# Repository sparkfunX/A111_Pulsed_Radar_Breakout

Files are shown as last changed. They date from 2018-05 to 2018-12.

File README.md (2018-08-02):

SparkX A111 Pulsed Radar Breakout
========================================

SparkX A111 Pulsed Radar Breakout (https://www.sparkfun.com/products/14811)

[*SparkX  A111 Pulsed Radar Breakout (SPX-14811)*](https://www.sparkfun.com/products/14811)

Does your project require high-precision, cutting-edge distance measurement? Or maybe speed-, motion-, or gesture-sensing? We’re not talking about simple ultrasonic, or even infrared, sensors here, but 60GHz radar! Well say hello to our tiny, pulsed-radar friend: the Acconeer A111.

The A111 is a single-chip solution for pulsed coherent radar (PCR). It comes complete with integrated antennae and an SPI interface capable of clock speeds of up to 50MHz. The A111’s primary use case is distance-sensing, but it also supports applications in gesture-, motion-, material-, and speed-detection. It can see objects at distances of up to two meters.

Our breakout board for the A111 includes a 1.8V regulator, voltage-level translation between 1.8V and either 3.3V or 5V, and, of course, it breaks out all pins of the pulsed radar sensor to both 0.1-inch and Raspberry Pi-friendly headers.

The breakout board is primarily **designed to interface directly with a Raspberry Pi** – Acconeer’s SDK currently only supports ARMv7’s (e.g. a Pi) and ARM Cortex-M4’s. Check out our <a href="https://learn.sparkfun.com/tutorials/using-the-a111-pulsed-radar-sensor-with-a-raspberry-pi">Using the A111 Pulsed Radar Breakout tutorial</a>, which explains how to use the sensor with a Raspberry Pi.

SparkFun labored with love to create this code. Feel like supporting open source hardware? 
Buy a [breakout board](https://www.sparkfun.com/products/14811) from SparkFun!

Repository Contents
-------------------

* **/Documents** - Datasheets
* **/Hardware** - Eagle design files (.brd, .sch)
* **/Software** - Example code and board-definition files to be added to the Acconeer ARMv7 SDK

License Information
-------------------

This product is _**open source**_! 

If you have any questions or concerns on licensing, please contact techsupport@sparkfun.com.

Please use, reuse, and modify these files as you see fit. Please maintain attribution to SparkFun Electronics and release any derivative under the same license.

Distributed as-is; no warranty is given.

- Your friends at SparkFun.

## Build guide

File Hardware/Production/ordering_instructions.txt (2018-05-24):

panel size, 148x173mm
PCB thickness, 1.6mm
number of layers, 2
soldermask color, Black
silkscreen color, White
oz copper, 1oz
finish, HASL lead free
stencils, top
pcs per panel, 16

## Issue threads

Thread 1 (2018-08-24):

Clarify that raspberry pi SPI needs to be enabled

ChristoSilvia, 2018-08-24:
I'm going through the tutorial now, and I was stuck when the Acconeer binaries didn't seem to be working.  After a while, I discovered that SPI was diabled by default in Raspbian.  It's easy to enable via "Raspberry" -> Preferences -> Raspberry Pi Configuration -> Interfaces, and clicking "enable" under the "SPI" line

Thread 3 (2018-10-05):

make error using spark example code on A1 SDK 1.3.9

uscgongjianxin, 2018-10-05:
I found the example code provided by Sparkfun was written for an earlier A1 SDK version (1.3.5) and the newer version (1.3.9) might have changed enough that it breaks the build. After I type "make" n terminal, I met this problem.

pi@raspberrypi:~/a111/evk_service_linux_armv7l_xc111_r4a_xr111-3_r1c_a111_r2c $ make
    Linking sparkx_envelope_service_example
lib/libacconeer_a111_r2c.a(acc_sensor_driver.o): In function `acc_hal_sensor_device_register_isr':
/home/anders/repos/sw-main/acconeer/sensor/sensor_driver/acc_sensor_driver.c:157: undefined reference to `acc_board_register_isr'
collect2: error: ld returned 1 exit status
rule/makefile_build_example_service_envelope_rpi_sparkx.inc:10: recipe for target 'out/sparkx_envelope_service_example' failed
make: *** [out/sparkx_envelope_service_example] Error 1

I cannot find the directory shown in the error message.
/home/anders/repos/sw-main/acconeer/sensor/sensor_driver/acc_sensor_driver.c

Does someone successfully build the program and get the radar data?

jkumaran, 2018-10-08:
I made a fork with updates in all 6 files of Software/sparkx-sdk-addon/ folder:
https://github.com/jkumaran/A111_Pulsed_Radar_Breakout
This fixed the problem and I was able to observe the radar results.

seasilvia, 2018-10-08:
I'm doing general troubleshooting, my board might just be dead.  I installed this code and make worked successfully:

```
pi@raspberrypi:~/a111/evk_service_linux_armv7l_xc112 $ make
    Compiling acc_board_rpi_sparkx.c
    Linking sparkx_envelope_service_example
    Linking sparkx_envelope_iq_example
    Linking sparkx_power_bins_example
    Compiling sparkx_detector_distance.c
    Linking sparkx_detector_distance
```

However, running the example service, I got "could not determine version:

```
Acconeer software version v1.3.9
Acconeer RSS version 1.0
13:27:03.832 [ 1669] (I) (rss): Radar system services activated
13:27:03.838 [ 1669] (I) (core_a111_r2c): Unknown sensor version 0x0000
13:27:03.838 [ 1669] (E) (session_sweep_and_processing): Could not determine version for sensor 1
13:27:03.838 [ 1669] (E) (session_sweep_and_processing): Sensor 1 not prepared
13:27:03.838 [ 1669] (I) (session_sweep_and_processing): acc_session_sweep_and_processing_destroy: Destroy confirmed
13:27:03.838 [ 1669] (E) (service_envelope): Session not created
acc_service_create failed
execute_envelope_with_blocking_calls() => (1) Failure unspecified
```

Any ideas? Could I have something misconfigured?

jimblom, 2018-10-09:
@jkumaran Thanks for your help. I've committed some changes that mostly reflect what you've done in your fork in the latest commit -- b114e95.

@seasilvia Can you give it a try with the latest updates to the include/source files?

jimblom, 2018-11-26:
@seasilvia I just pushed some changes in commit c4784f2 that should make the makefile rules and examples compatible with A111 SDK v1.3.11. Give it a try and see if it fixes your board. Feel free to re-open if it's still giving you trouble.

@jkumaran -- Sorry I didn't check this issue first to find your fixes... Thanks for your help!

Closed 2018-11-26.

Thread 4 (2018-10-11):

Coordinates system of A111

uscgongjianxin, 2018-10-11:
Now I obtained outputs like this
Distance detector: Reflections: 5. Seq. nr: 424. (200-700 mm): 648 mm (137), 658 mm (250), 665 mm (255), 676 mm (209), 686 mm (65).

But since I don't know the coordinates system of A111,  I don't know the meaning of the amplitude of the reflection. What is x-axis? What is y-axis? Where is the origin? The amplitude should be an angle between an axis and the line connecting the origin and the object.

pthorell, 2018-11-28:
The A111 sensor measures the reflected energy at different radial distances from the sensor. Good reflectors reflect more energy to the sensor which results in a high amplitude in the received signal.

For more information see chapter 5 in the “Envelope service user guide” [https://download.acconeer.com/doc/Envelope%20Service%20User%20Guide](https://download.acconeer.com/doc/Envelope%20Service%20User%20Guide) .

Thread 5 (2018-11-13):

make error using spark example code on A1 SDK 1.3.11

hpritchett, 2018-11-13:
I am getting this error when I run make:
make: *** No rule to make target 'out/example_service_envelope.o', needed by 'out/sparkx_envelope_service_example'.  Stop.

Using the following sdk:
acconeer_evk_service_linux_armv7l_xc111_r4a_xr111-3_r1c_a111_r2c_v1_3_11

The build only fails if I add the A111_Pulsed_Radar_Breakout software addon.
Does anyone have SDK 1.3.9? Or know what I need to do to fix this?

jimblom, 2018-11-26:
Sorry about the delay. I've made some fixes to the rules and board source files in commit c4784f2.

All examples should be compatible with the latest A111 SDK: v1.3.11.

Closed 2018-11-26.

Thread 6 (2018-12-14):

Please Update for SDK 1.4.0

kbooth-insight, 2018-12-14:
The code doesn't build with the most recent SDK:

```
pi@raspberrypi:~/evk_service_linux_armv7l_xc111_r4a_xr111-3_r1c_a111_r2c $ make
    Compiling acc_board_rpi_sparkx.c
source/acc_board_rpi_sparkx.c: In function ‘acc_board_init’:
source/acc_board_rpi_sparkx.c:177:2: error: too few arguments to function ‘acc_driver_gpio_linux_sysfs_register’
  acc_driver_gpio_linux_sysfs_register(28);
  ^~~~~~~~~~~~~~~~~~~~~~~~~~~~~~~~~~~~
In file included from source/acc_board_rpi_sparkx.c:12:0:
include/acc_driver_gpio_linux_sysfs.h:51:13: note: declared here
 extern void acc_driver_gpio_linux_sysfs_register(uint_fast16_t pin_count, gpio_t *gpio_mem);
             ^~~~~~~~~~~~~~~~~~~~~~~~~~~~~~~~~~~~
makefile:60: recipe for target 'out/obj/acc_board_rpi_sparkx.o' failed
```

I tried setting up the new gpio_t param myself, and I end up hard-locking the Pi.

jimblom, 2018-12-20:
Thanks for the heads up!

I've pushed some new changes to source/acc_board_rpi_sparkx.c in commit dbbd525. Should update the addon files to work with SDK 1.4.0.

Feel free to re-open if it's still giving you trouble.

kbooth-insight, 2018-12-21:
Thanks much for updating!

I'm not sure if I should ask this here or over at the sparkfun forums, but after pulling this update and building, I seem to get calibration errors.  The sensor initializes correctly it seems,

Here is some example output:
```
pi@raspberrypi:~/evk_service_linux_armv7l_xc111_r4a_xr111-3_r1c_a111_r2c/out $ ./sparkx_detector_distance
Acconeer software version v1.4.0
Acconeer RSS version 1.0
20:00:23.271 [10508] (I) (rss): Radar system services activated

A111 Initialized

Press ENTER to run distance detection...
Running distance peak detector in blocking mode
20:00:29.367 [10508] (E) (sensor_protocol): Timeout waiting for interrupt.
20:00:29.367 [10508] (E) (sensor_protocol): Timeout waiting for indication on sensor 1.
20:00:29.368 [10508] (I) (sensor_protocol): Run_status running at : 1c2
20:00:29.368 [10508] (I) (sensor_protocol): Run_status running at : 1c2
20:00:29.368 [10508] (I) (sensor_protocol): Run_status running at : 1c2
<snip>
20:00:29.373 [10508] (I) (sensor_protocol): Run_status running at : 1c2
20:00:29.373 [10508] (I) (sensor_protocol): Run_status running at : 1c2
20:00:29.373 [10508] (I) (sensor_protocol): Interrupt_status_register: 80
20:00:29.373 [10508] (I) (sensor_protocol): WakeupInput[7..0]_wakeup_config: 0 24 0 0 0 0 0 0
20:00:29.373 [10508] (I) (sensor_protocol): Inputmux_wakeupinput[7..0]_config : 0 13 0 0 0 0 0 8
20:00:29.373 [10508] (I) (sensor_protocol): Timer[3..0]_wakeup_config: 0 0 0 0
20:00:29.374 [10508] (I) (sensor_protocol): asic_identity_number: 4370, run_status: 1474, interrupt_status: 80, Scratchpad Config 7: 3
20:00:29.374 [10508] (I) (sensor_protocol): Wakeup_status0_register: 1
20:00:29.374 [10508] (I) (sensor_protocol): asic_error_status : 0
20:00:29.374 [10508] (I) (sensor_protocol): Stack_level_status_register: 0
20:00:29.374 [10508] (I) (sensor_protocol): Stack level 0: Addr=450
20:00:29.374 [10508] (I) (sensor_protocol): Stack level 1: Addr=449 Loop=0
20:00:29.374 [10508] (I) (sensor_protocol): Stack level 2: Addr=468 Loop=0
20:00:29.374 [10508] (I) (sensor_protocol): Stack level 3: Addr=0 Loop=0
20:00:29.374 [10508] (I) (sensor_protocol): Stack level 4: Addr=0 Loop=0
20:00:29.374 [10508] (I) (sensor_protocol): Stack level 5: Addr=0 Loop=0
20:00:29.374 [10508] (I) (sensor_protocol): Stack level 6: Addr=0 Loop=0
20:00:29.374 [10508] (I) (sensor_protocol): Stack level 7: Addr=0 Loop=0
20:00:29.374 [10508] (I) (sensor_protocol): vco_cbank_config: 4
20:00:29.374 [10508] (I) (sensor_protocol): pll_config: 127
20:00:29.374 [10508] (I) (sensor_protocol): Pll_div_config: 9
20:00:29.375 [10508] (E) (cbank_calibration_manager): Failed to retrieve indication.
20:00:29.375 [10508] (E) (cbank_calibration_manager): Failed to get result.
20:00:29.375 [10508] (E) (core_a111_r2c): CBank calibration failure.
20:00:29.375 [10508] (E) (session_sweep_and_processing): Sensor calibration failure for sensor 1.
Free space absolute offset: 4294967295 mm
Actual start: 4294967295 mm
Actual length: 4294967295 mm
Actual end: 4294967295 mm

20:00:29.375 [10508] (E) (service): Configuration: Invalid handle.
acc_service_activate() failed
20:00:29.375 [10508] (E) (service): Configuration: Invalid handle.
Running distance peak detector in blocking mode failed
Press ENTER to calculate THRESHOLD and run peak detection...
Running distance peak detector in blocking mode with estimated threshold
20:00:42.455 [10508] (E) (sensor_protocol): Timeout waiting for interrupt.
20:00:42.455 [10508] (E) (sensor_protocol): Timeout waiting for indication on sensor 1.
20:00:42.455 [10508] (I) (sensor_protocol): Run_status running at : 1c2
20:00:42.455 [10508] (I) (sensor_protocol): Run_status running at : 1c2
20:00:42.455 [10508] (I) (sensor_protocol): Run_status running at : 1c2
20:00:42.455 [10508] (I) (sensor_protocol): Run_status running at : 1c2
<snip>
20:00:42.460 [10508] (I) (sensor_protocol): Run_status running at : 1c2
20:00:42.460 [10508] (I) (sensor_protocol): Run_status running at : 1c2
20:00:42.460 [10508] (I) (sensor_protocol): Run_status running at : 1c2
20:00:42.460 [10508] (I) (sensor_protocol): Interrupt_status_register: 80
20:00:42.461 [10508] (I) (sensor_protocol): WakeupInput[7..0]_wakeup_config: 0 24 0 0 0 0 0 0
20:00:42.461 [10508] (I) (sensor_protocol): Inputmux_wakeupinput[7..0]_config : 0 13 0 0 0 0 0 8
20:00:42.461 [10508] (I) (sensor_protocol): Timer[3..0]_wakeup_config: 0 0 0 0
20:00:42.461 [10508] (I) (sensor_protocol): asic_identity_number: 4370, run_status: 1474, interrupt_status: 80, Scratchpad Config 7: 3
20:00:42.461 [10508] (I) (sensor_protocol): Wakeup_status0_register: 1
20:00:42.461 [10508] (I) (sensor_protocol): asic_error_status : 0
20:00:42.461 [10508] (I) (sensor_protocol): Stack_level_status_register: 0
20:00:42.461 [10508] (I) (sensor_protocol): Stack level 0: Addr=450
20:00:42.461 [10508] (I) (sensor_protocol): Stack level 1: Addr=449 Loop=0
20:00:42.461 [10508] (I) (sensor_protocol): Stack level 2: Addr=468 Loop=0
20:00:42.461 [10508] (I) (sensor_protocol): Stack level 3: Addr=0 Loop=0
20:00:42.462 [10508] (I) (sensor_protocol): Stack level 4: Addr=0 Loop=0
20:00:42.462 [10508] (I) (sensor_protocol): Stack level 5: Addr=0 Loop=0
20:00:42.462 [10508] (I) (sensor_protocol): Stack level 6: Addr=0 Loop=0
20:00:42.462 [10508] (I) (sensor_protocol): Stack level 7: Addr=0 Loop=0
20:00:42.462 [10508] (I) (sensor_protocol): vco_cbank_config: 4
20:00:42.462 [10508] (I) (sensor_protocol): pll_config: 127
20:00:42.462 [10508] (I) (sensor_protocol): Pll_div_config: 9
20:00:42.462 [10508] (E) (cbank_calibration_manager): Failed to retrieve indication.
20:00:42.462 [10508] (E) (cbank_calibration_manager): Failed to get result.
20:00:42.462 [10508] (E) (core_a111_r2c): CBank calibration failure.
20:00:42.462 [10508] (E) (session_sweep_and_processing): Sensor calibration failure for sensor 1.
Free space absolute offset: 4294967295 mm
Actual start: 4294967295 mm
Actual length: 4294967295 mm
Actual end: 4294967295 mm

Estimating threshold...
20:00:42.462 [10508] (E) (service): Configuration: Invalid handle.
20:00:42.462 [10508] (E) (acc_detector_distance_peak): Threshold estimation update failed
Estimating threshold done...

Press ENTER to measure threshold-ed distance
Then press CTRL+C to STOP

20:00:46.345 [10508] (E) (service): Configuration: Invalid handle.
acc_service_activate() failed
20:00:46.345 [10508] (W) (acc_detector_distance_peak): Detector is already inactive
20:00:46.345 [10508] (E) (service): Configuration: Invalid handle.
20:00:46.345 [10508] (I) (rss): Radar system services deactivated
```

Any help would be greatly appreciated!

jimblom, 2018-12-21:
Oof, at a glance, I'm not sure -- haven't seen those errors before.

If you don't mind opening a new issue with this, I'd be happy to look into it.

Closed 2018-12-20.

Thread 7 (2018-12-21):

Calibration error using SDK 1.4

kbooth-insight, 2018-12-21:
Opening new issue per advice, really appreciate the assistance.   If you haven't seen this error before, I'm leaning towards my soldering job :(

I'm not sure if I should ask this here or over at the sparkfun forums, but after pulling this update and building, I seem to get calibration errors. The sensor initializes correctly it seems,

Here is some example output:

```
pi@raspberrypi:~/evk_service_linux_armv7l_xc111_r4a_xr111-3_r1c_a111_r2c/out $ ./sparkx_detector_distance
Acconeer software version v1.4.0
Acconeer RSS version 1.0
20:00:23.271 [10508] (I) (rss): Radar system services activated

A111 Initialized

Press ENTER to run distance detection...
Running distance peak detector in blocking mode
20:00:29.367 [10508] (E) (sensor_protocol): Timeout waiting for interrupt.
20:00:29.367 [10508] (E) (sensor_protocol): Timeout waiting for indication on sensor 1.
20:00:29.368 [10508] (I) (sensor_protocol): Run_status running at : 1c2
20:00:29.368 [10508] (I) (sensor_protocol): Run_status running at : 1c2
20:00:29.368 [10508] (I) (sensor_protocol): Run_status running at : 1c2
<snip>
20:00:29.373 [10508] (I) (sensor_protocol): Run_status running at : 1c2
20:00:29.373 [10508] (I) (sensor_protocol): Run_status running at : 1c2
20:00:29.373 [10508] (I) (sensor_protocol): Interrupt_status_register: 80
20:00:29.373 [10508] (I) (sensor_protocol): WakeupInput[7..0]_wakeup_config: 0 24 0 0 0 0 0 0
20:00:29.373 [10508] (I) (sensor_protocol): Inputmux_wakeupinput[7..0]_config : 0 13 0 0 0 0 0 8
20:00:29.373 [10508] (I) (sensor_protocol): Timer[3..0]_wakeup_config: 0 0 0 0
20:00:29.374 [10508] (I) (sensor_protocol): asic_identity_number: 4370, run_status: 1474, interrupt_status: 80, Scratchpad Config 7: 3
20:00:29.374 [10508] (I) (sensor_protocol): Wakeup_status0_register: 1
20:00:29.374 [10508] (I) (sensor_protocol): asic_error_status : 0
20:00:29.374 [10508] (I) (sensor_protocol): Stack_level_status_register: 0
20:00:29.374 [10508] (I) (sensor_protocol): Stack level 0: Addr=450
20:00:29.374 [10508] (I) (sensor_protocol): Stack level 1: Addr=449 Loop=0
20:00:29.374 [10508] (I) (sensor_protocol): Stack level 2: Addr=468 Loop=0
20:00:29.374 [10508] (I) (sensor_protocol): Stack level 3: Addr=0 Loop=0
20:00:29.374 [10508] (I) (sensor_protocol): Stack level 4: Addr=0 Loop=0
20:00:29.374 [10508] (I) (sensor_protocol): Stack level 5: Addr=0 Loop=0
20:00:29.374 [10508] (I) (sensor_protocol): Stack level 6: Addr=0 Loop=0
20:00:29.374 [10508] (I) (sensor_protocol): Stack level 7: Addr=0 Loop=0
20:00:29.374 [10508] (I) (sensor_protocol): vco_cbank_config: 4
20:00:29.374 [10508] (I) (sensor_protocol): pll_config: 127
20:00:29.374 [10508] (I) (sensor_protocol): Pll_div_config: 9
20:00:29.375 [10508] (E) (cbank_calibration_manager): Failed to retrieve indication.
20:00:29.375 [10508] (E) (cbank_calibration_manager): Failed to get result.
20:00:29.375 [10508] (E) (core_a111_r2c): CBank calibration failure.
20:00:29.375 [10508] (E) (session_sweep_and_processing): Sensor calibration failure for sensor 1.
Free space absolute offset: 4294967295 mm
Actual start: 4294967295 mm
Actual length: 4294967295 mm
Actual end: 4294967295 mm

20:00:29.375 [10508] (E) (service): Configuration: Invalid handle.
acc_service_activate() failed
20:00:29.375 [10508] (E) (service): Configuration: Invalid handle.
Running distance peak detector in blocking mode failed
Press ENTER to calculate THRESHOLD and run peak detection...
Running distance peak detector in blocking mode with estimated threshold
20:00:42.455 [10508] (E) (sensor_protocol): Timeout waiting for interrupt.
20:00:42.455 [10508] (E) (sensor_protocol): Timeout waiting for indication on sensor 1.
20:00:42.455 [10508] (I) (sensor_protocol): Run_status running at : 1c2
20:00:42.455 [10508] (I) (sensor_protocol): Run_status running at : 1c2
20:00:42.455 [10508] (I) (sensor_protocol): Run_status running at : 1c2
20:00:42.455 [10508] (I) (sensor_protocol): Run_status running at : 1c2
<snip>
20:00:42.460 [10508] (I) (sensor_protocol): Run_status running at : 1c2
20:00:42.460 [10508] (I) (sensor_protocol): Run_status running at : 1c2
20:00:42.460 [10508] (I) (sensor_protocol): Run_status running at : 1c2
20:00:42.460 [10508] (I) (sensor_protocol): Interrupt_status_register: 80
20:00:42.461 [10508] (I) (sensor_protocol): WakeupInput[7..0]_wakeup_config: 0 24 0 0 0 0 0 0
20:00:42.461 [10508] (I) (sensor_protocol): Inputmux_wakeupinput[7..0]_config : 0 13 0 0 0 0 0 8
20:00:42.461 [10508] (I) (sensor_protocol): Timer[3..0]_wakeup_config: 0 0 0 0
20:00:42.461 [10508] (I) (sensor_protocol): asic_identity_number: 4370, run_status: 1474, interrupt_status: 80, Scratchpad Config 7: 3
20:00:42.461 [10508] (I) (sensor_protocol): Wakeup_status0_register: 1
20:00:42.461 [10508] (I) (sensor_protocol): asic_error_status : 0
20:00:42.461 [10508] (I) (sensor_protocol): Stack_level_status_register: 0
20:00:42.461 [10508] (I) (sensor_protocol): Stack level 0: Addr=450
20:00:42.461 [10508] (I) (sensor_protocol): Stack level 1: Addr=449 Loop=0
20:00:42.461 [10508] (I) (sensor_protocol): Stack level 2: Addr=468 Loop=0
20:00:42.461 [10508] (I) (sensor_protocol): Stack level 3: Addr=0 Loop=0
20:00:42.462 [10508] (I) (sensor_protocol): Stack level 4: Addr=0 Loop=0
20:00:42.462 [10508] (I) (sensor_protocol): Stack level 5: Addr=0 Loop=0
20:00:42.462 [10508] (I) (sensor_protocol): Stack level 6: Addr=0 Loop=0
20:00:42.462 [10508] (I) (sensor_protocol): Stack level 7: Addr=0 Loop=0
20:00:42.462 [10508] (I) (sensor_protocol): vco_cbank_config: 4
20:00:42.462 [10508] (I) (sensor_protocol): pll_config: 127
20:00:42.462 [10508] (I) (sensor_protocol): Pll_div_config: 9
20:00:42.462 [10508] (E) (cbank_calibration_manager): Failed to retrieve indication.
20:00:42.462 [10508] (E) (cbank_calibration_manager): Failed to get result.
20:00:42.462 [10508] (E) (core_a111_r2c): CBank calibration failure.
20:00:42.462 [10508] (E) (session_sweep_and_processing): Sensor calibration failure for sensor 1.
Free space absolute offset: 4294967295 mm
Actual start: 4294967295 mm
Actual length: 4294967295 mm
Actual end: 4294967295 mm

Estimating threshold...
20:00:42.462 [10508] (E) (service): Configuration: Invalid handle.
20:00:42.462 [10508] (E) (acc_detector_distance_peak): Threshold estimation update failed
Estimating threshold done...

Press ENTER to measure threshold-ed distance
Then press CTRL+C to STOP

20:00:46.345 [10508] (E) (service): Configuration: Invalid handle.
acc_service_activate() failed
20:00:46.345 [10508] (W) (acc_detector_distance_peak): Detector is already inactive
20:00:46.345 [10508] (E) (service): Configuration: Invalid handle.
20:00:46.345 [10508] (I) (rss): Radar system services deactivated

```

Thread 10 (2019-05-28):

About Pi Zero W...

gn01658704, 2019-05-28:
Hello everyone
I have a question I want to ask.
Can this module work on Pi Zero W?

Kotdnz, 2023-02-15:
Let me share the results of my investigation.
I have the board Raspberry Pi Zero Rev 1.3
Within CCPU model name	: ARMv6-compatible processor rev 7 (v6l)
To build the examples we must have two precompiled libraries in ~/rpi_sparkfun/lib $
7446 2772 -rw-r--r--  1 pi pi 2835722 Jan  9 16:44 libacconeer.a
7467  324 -rw-r--r--  1 pi pi  331494 Jan  9 16:44 libacconeer_exploration_server_a111.a
$ readelf -A libacconeer.a
  Tag_CPU_name: "7-A"
  Tag_CPU_arch: v7
  Tag_CPU_arch_profile: Application
  Tag_ARM_ISA_use: Yes
  Tag_THUMB_ISA_use: Thumb-2

But our board is able to work only with
  Tag_CPU_name: "6"
  Tag_CPU_arch: v6
  Tag_ARM_ISA_use: Yes
  Tag_THUMB_ISA_use: Thumb-1

Thus, when we are trying to run we yield the following:
~/rpi_sparkfun $ out/example_bring_up
Acconeer software version a111-v2.14.1
Illegal instruction

Unfortunately, I can't find the library for armv6l....
Presumably, all should works fine on Zero 2

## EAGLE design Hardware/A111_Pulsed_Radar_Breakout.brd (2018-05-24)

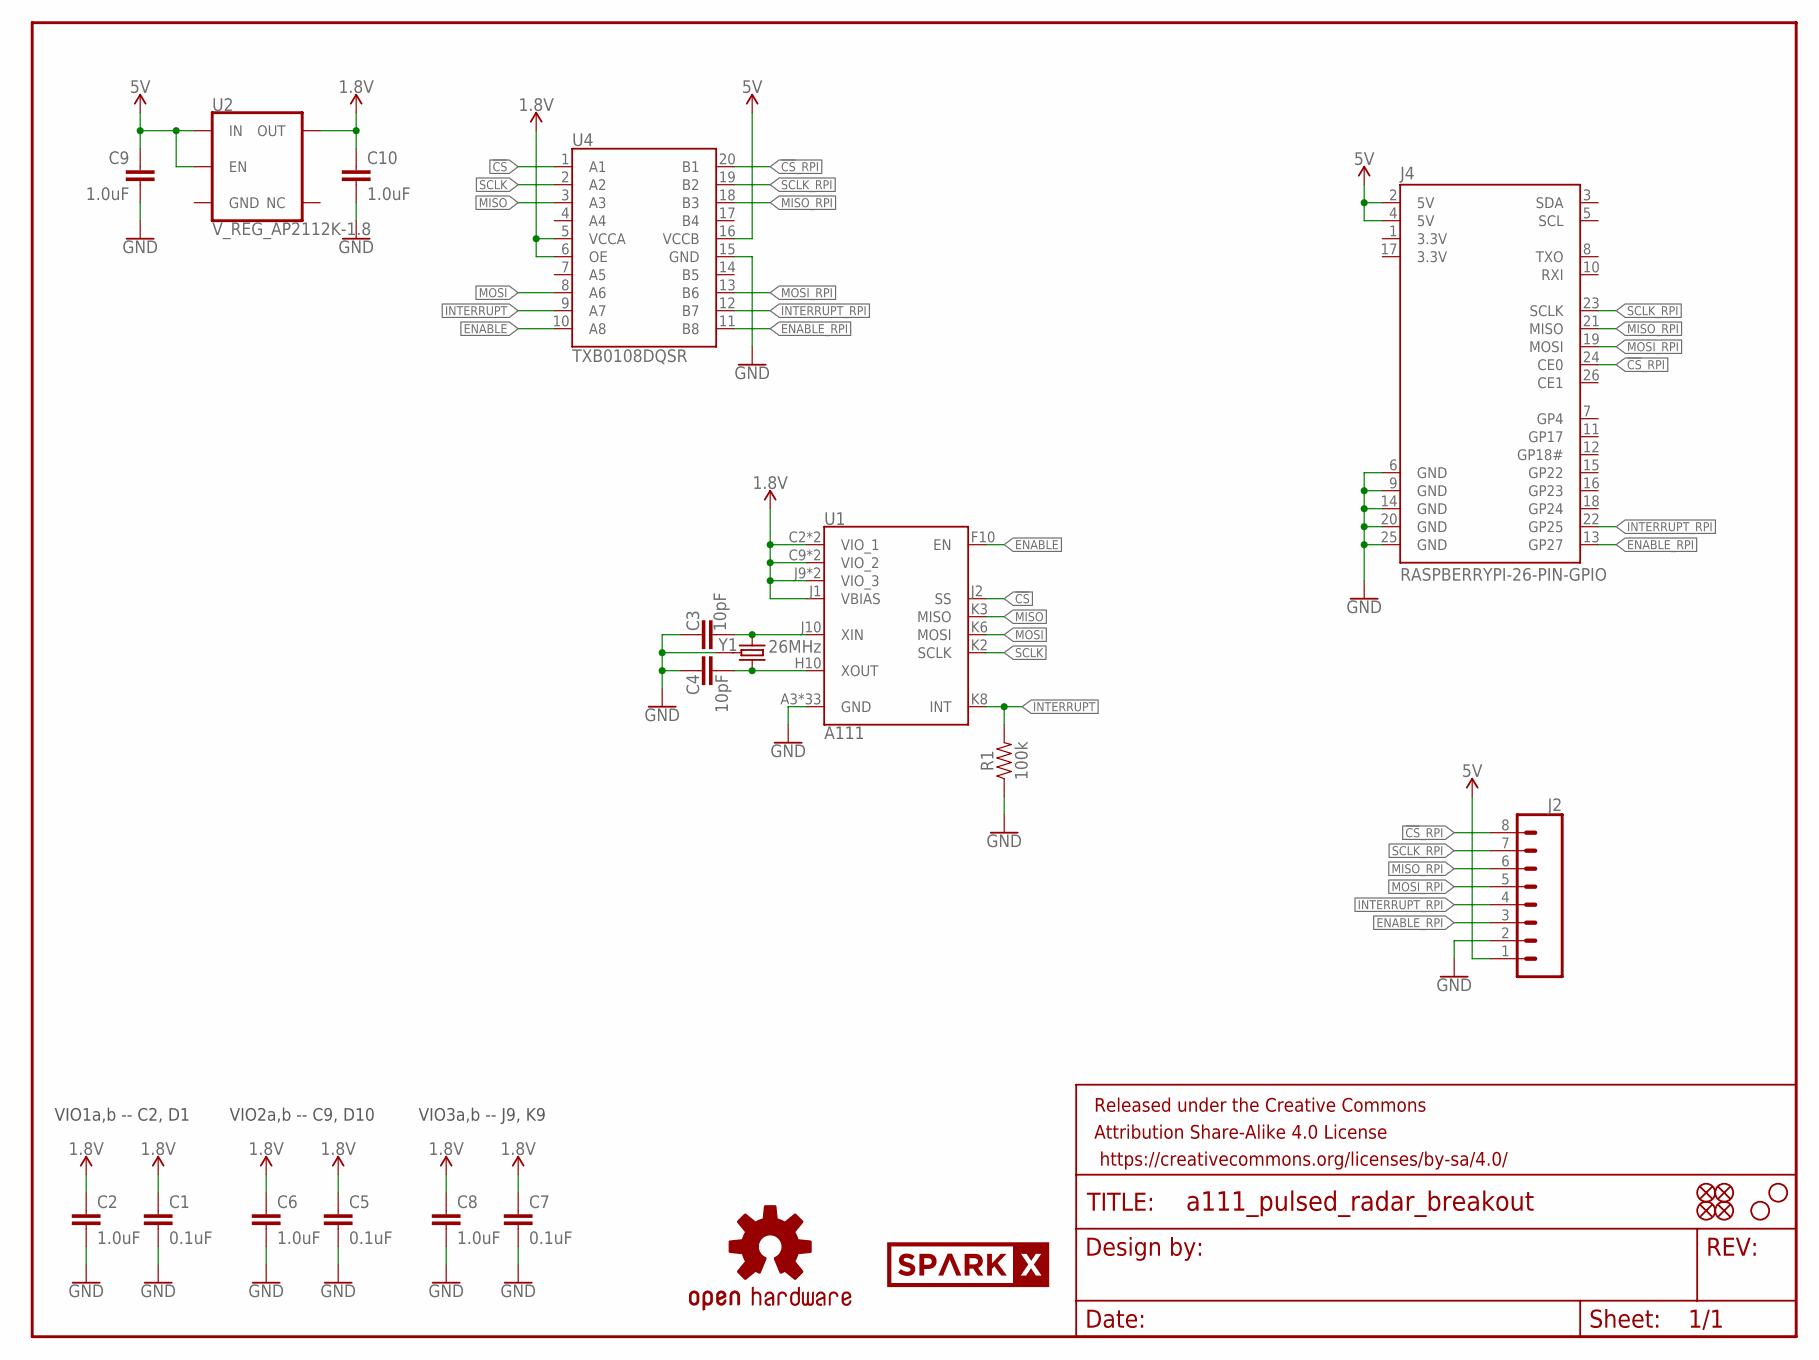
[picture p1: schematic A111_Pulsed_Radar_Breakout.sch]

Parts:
C1, C5, C7: 0.1uF; 0603
C2, C6, C8, C9, C10: 1.0uF; 0603
C3, C4: 10pF; 0603
FD1, FD2, FD3, FD4: FIDUCIALUFIDUCIAL; FIDUCIAL-MICRO
FRAME1: FRAME-LETTER; CREATIVE_COMMONS
H1, H2: STAND-OFF
J2: CONN_08NO_SILK_FEMALE_PTH; 1X08_NO_SILK
J4: RASPBERRYPI-26-PIN-GPIO; 2X13
LOGO1: SPARKX-LOGO5; SPARKX-LARGE
LOGO2: OSHW-LOGOM; OSHW-LOGO-M
R1: 100k; 0603
U1: A111
U2: V_REG_AP2112K-1.8; SOT23-5
U4: TXB0108DQSR; UFDFN-20
Y1: 26MHz; CRYSTAL-SMD-3.2X2.5MM

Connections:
1.8V: C1.1, C2.1, C5.1, C6.1, C7.1, C8.1, C10.1, U1.C2 (VIO_1), U1.C9 (VIO_2), U1.D1 (VIO_1), U1.D10 (VIO_2), U1.J1 (VBIAS), U1.J9 (VIO_3), U1.K9 (VIO_3), U2.5 (OUT), U4.5 (VCCA), U4.6 (OE)
5V: C9.1, J2.1, J4.2 (5V), J4.4 (5V), U2.1 (IN), U2.3 (EN), U4.16 (VCCB)
!CS!: U1.J2 (SS), U4.1 (A1)
!CS!_RPI: J2.8, J4.24 (CE0), U4.20 (B1)
ENABLE: U1.F10 (EN), U4.10 (A8)
ENABLE_RPI: J2.3, J4.13 (GP27), U4.11 (B8)
GND: C1.2, C2.2, C3.2, C4.1, C5.2, C6.2, C7.2, C8.2, C9.2, C10.2, J2.2, J4.6 (GND), J4.9 (GND), J4.14 (GND), J4.20 (GND), J4.25 (GND), R1.1, U1.A3 (GND), U1.A4 (GND), U1.A5 (GND), U1.A6 (GND), U1.A7 (GND), U1.A8 (GND), U1.A9 (GND), U1.B2 (GND), U1.B9 (GND), U1.B10 (GND), U1.C1 (GND), U1.C10 (GND), U1.D2 (GND), U1.D9 (GND), U1.E1 (GND), U1.E2 (GND), U1.E9 (GND), U1.E10 (GND), U1.F1 (GND), U1.F2 (GND), U1.F9 (GND), U1.G1 (GND), U1.G10 (GND), U1.H1 (GND), U1.H2 (GND), U1.H9 (GND), U1.J3 (GND), U1.J5 (GND), U1.J6 (GND), U1.J8 (GND), U1.K4 (GND), U1.K5 (GND), U1.K7 (GND), U4.15 (GND), Y1.2 (3), Y1.4 (3)
INTERRUPT: R1.2, U1.K8 (INT), U4.9 (A7)
INTERRUPT_RPI: J2.4, J4.22 (GP25), U4.12 (B7)
MISO: U1.K3 (MISO), U4.3 (A3)
MISO_RPI: J2.6, J4.21 (MISO), U4.18 (B3)
MOSI: U1.K6 (MOSI), U4.8 (A6)
MOSI_RPI: J2.5, J4.19 (MOSI), U4.13 (B6)
unnamed: C3.1, U1.J10 (XIN), Y1.1
unnamed: C4.2, U1.H10 (XOUT), Y1.3 (2)
SCLK: U1.K2 (SCLK), U4.2 (A2)
SCLK_RPI: J2.7, J4.23 (SCLK), U4.19 (B2)

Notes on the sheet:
VIO1a,b -- C2, D1
VIO2a,b -- C9, D10
VIO3a,b -- J9, K9

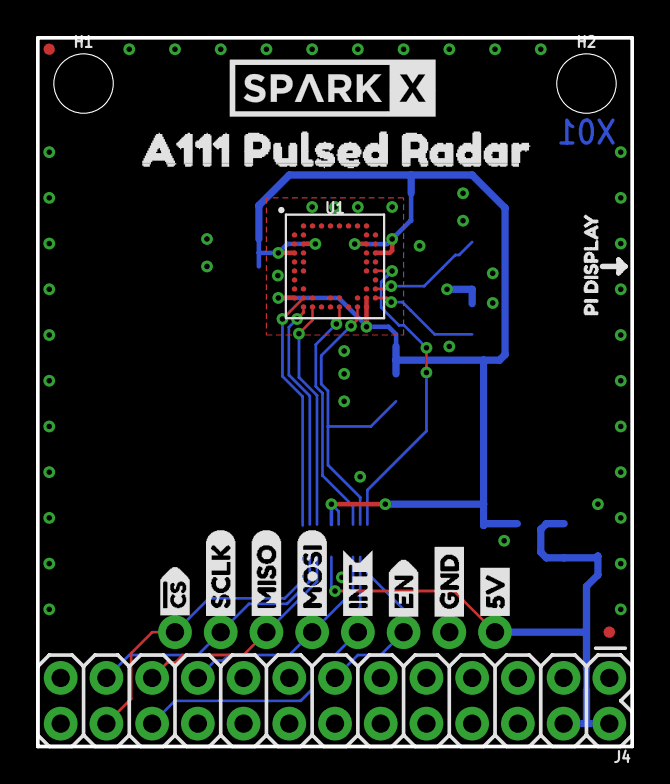
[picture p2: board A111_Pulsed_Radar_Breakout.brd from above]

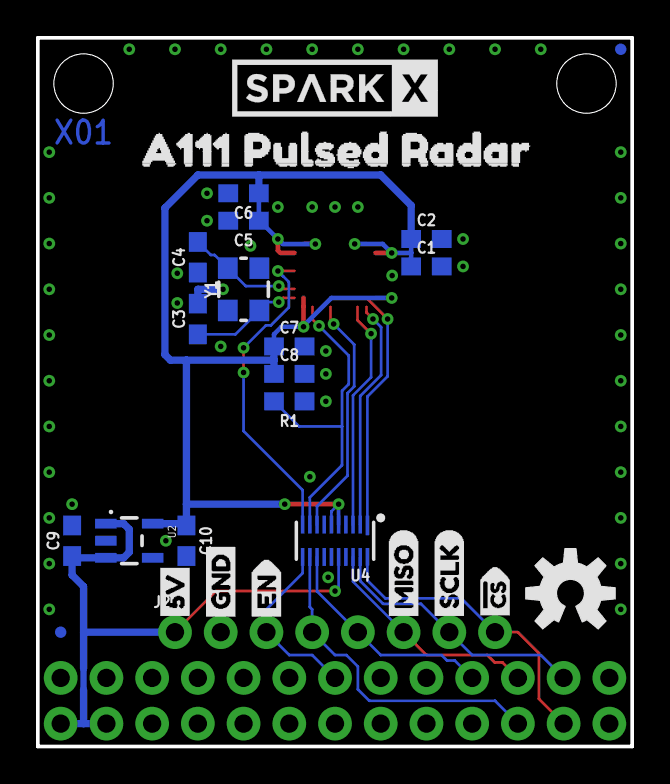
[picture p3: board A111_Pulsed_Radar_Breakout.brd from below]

Board: 2 copper layers, 33.0 x 39.4 mm, 44 parts (26 on the bottom side), 17 nets.

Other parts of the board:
LOGO3: SPARKX-LOGO5; SPARKX-LARGE
U$1, U$9: A111_PULSED_RADAR9
U$2, U$10: SCLK3
U$3, U$11: MISO4
U$4: MOSI5
U$5: INT8
U$6, U$18: EN9
U$7, U$15: GND0
U$8, U$16: 5V1
U$12: PI_DISPLAY9
U$13, U$17: #CS9

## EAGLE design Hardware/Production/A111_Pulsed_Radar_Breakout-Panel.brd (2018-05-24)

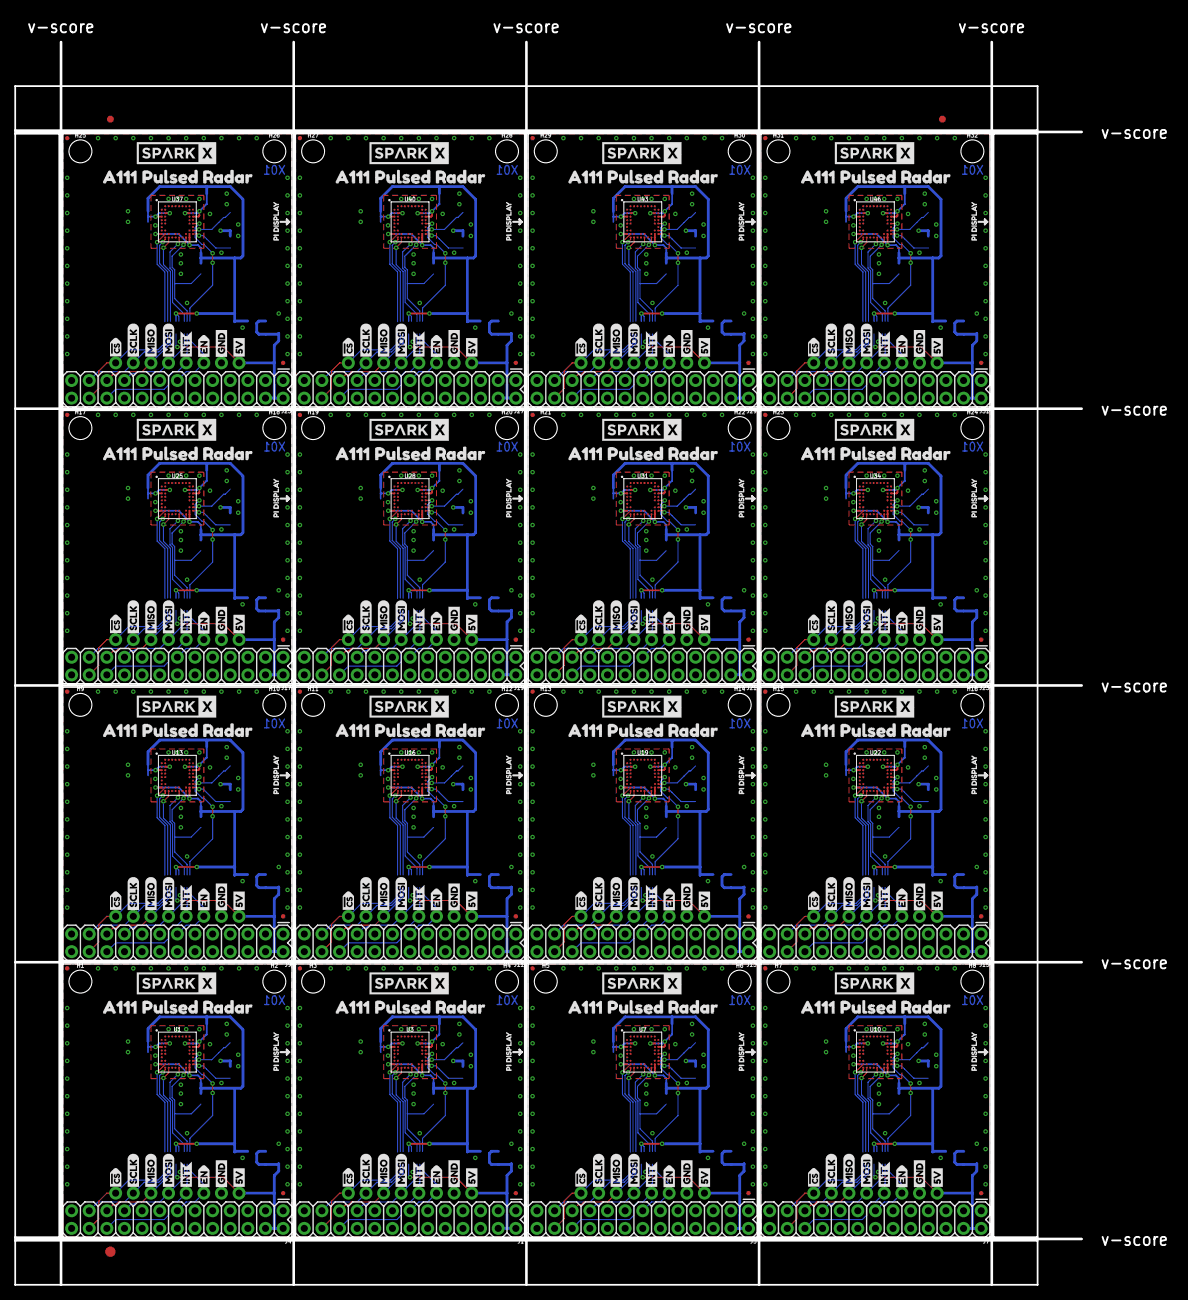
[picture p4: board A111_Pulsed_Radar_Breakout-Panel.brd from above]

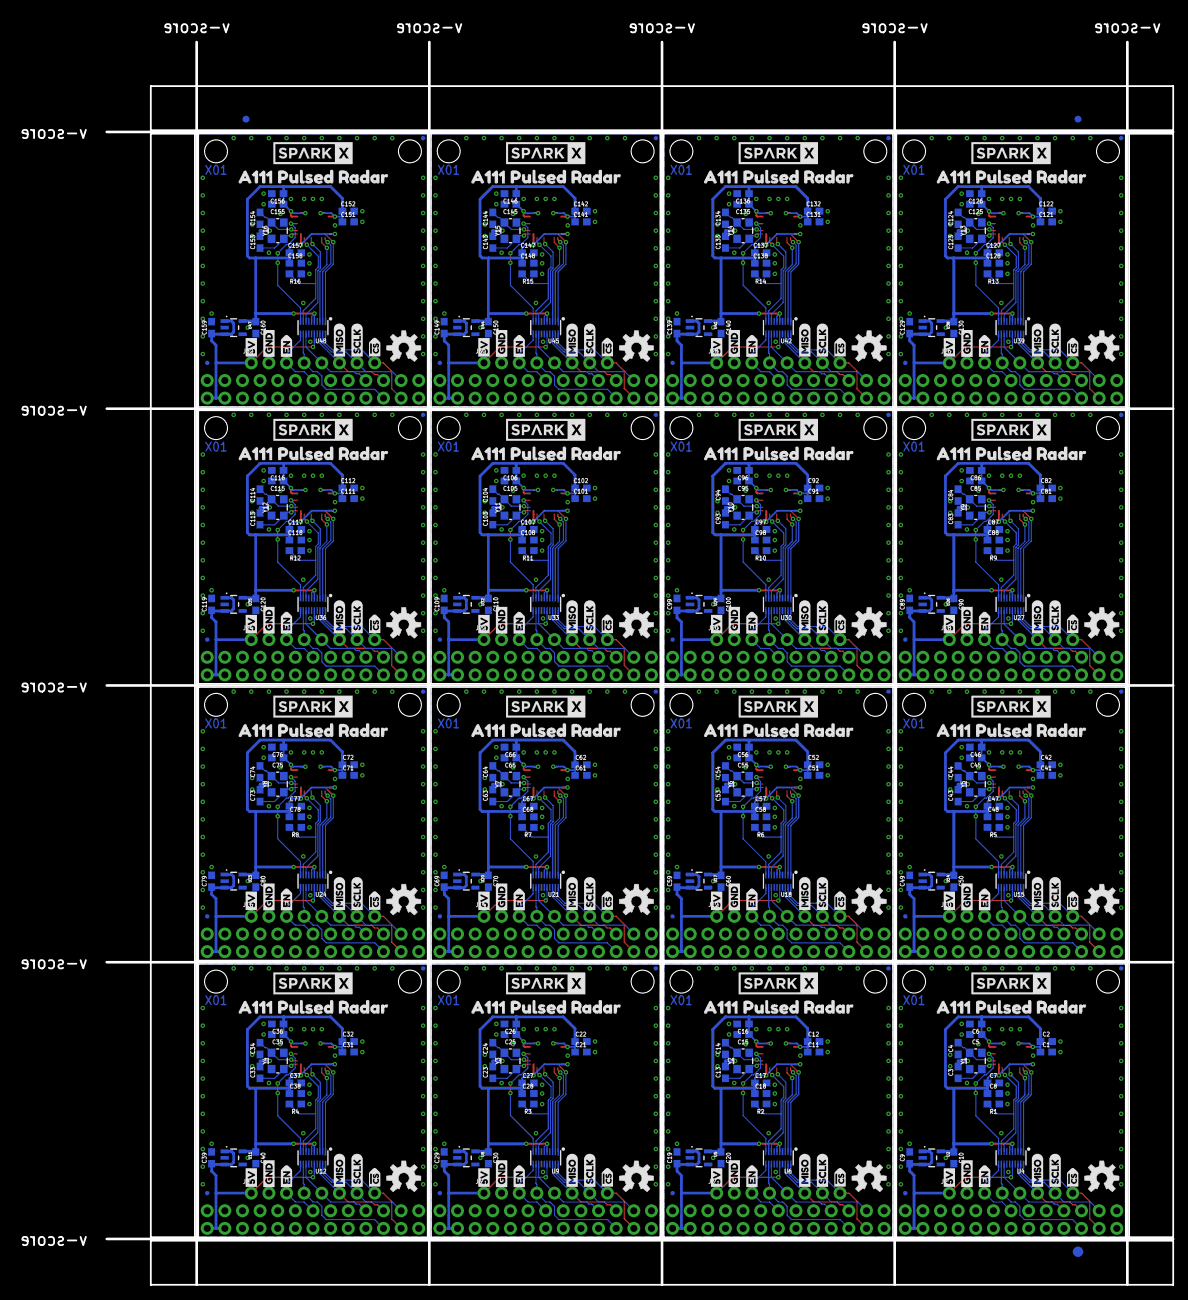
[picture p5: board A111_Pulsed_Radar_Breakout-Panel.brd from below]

Board: 2 copper layers, 153.7 x 179.1 mm, 694 parts (419 on the bottom side), 272 nets.

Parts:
C1, C5, C7, C11, C15, C17, C21, C25, C27, C31, C35, C37, C41, C45, C47, C51, C55, C57, C61, C65, C67, C71, C75, C77, C81, C85, C87, C91, C95, C97, C101, C105, C107, C111, C115, C117, C121, C125, C127, C131, C135, C137, C141, C145, C147, C151, C155, C157: 0.1uF; 0603
C2, C6, C8, C9, C10, C12, C16, C18, C19, C20, C22, C26, C28, C29, C30, C32, C36, C38, C39, C40, C42, C46, C48, C49, C50, C52, C56, C58, C59, C60, C62, C66, C68, C69, C70, C72, C76, C78, C79, C80, C82, C86, C88, C89, C90, C92, C96, C98, C99, C100, C102, C106, C108, C109, C110, C112, C116, C118, C119, C120, C122, C126, C128, C129, C130, C132, C136, C138, C139, C140, C142, C146, C148, C149, C150, C152, C156, C158, C159, C160: 1.0uF; 0603
C3, C4, C13, C14, C23, C24, C33, C34, C43, C44, C53, C54, C63, C64, C73, C74, C83, C84, C93, C94, C103, C104, C113, C114, C123, C124, C133, C134, C143, C144, C153, C154: 10pF; 0603
E$1, E$2, E$3, E$4: FIDUCIAL-1X2
E$5, E$6: FIDUCIAL-1.5X3
FD1, FD2, FD3, FD4, FD5, FD6, FD7, FD8, FD9, FD10, FD11, FD12, FD13, FD14, FD15, FD16, FD17, FD18, FD19, FD20, FD21, FD22, FD23, FD24, FD25, FD26, FD27, FD28, FD29, FD30, FD31, FD32, FD33, FD34, FD35, FD36, FD37, FD38, FD39, FD40, FD41, FD42, FD43, FD44, FD45, FD46, FD47, FD48, FD49, FD50, FD51, FD52, FD53, FD54, FD55, FD56, FD57, FD58, FD59, FD60, FD61, FD62, FD63, FD64: FIDUCIALUFIDUCIAL; FIDUCIAL-MICRO
H1, H2, H3, H4, H5, H6, H7, H8, H9, H10, H11, H12, H13, H14, H15, H16, H17, H18, H19, H20, H21, H22, H23, H24, H25, H26, H27, H28, H29, H30, H31, H32: STAND-OFF
J1, J4, J5, J7, J9, J11, J13, J15, J17, J19, J21, J23, J25, J27, J29, J31: RASPBERRYPI-26-PIN-GPIO; 2X13
J2, J3, J6, J8, J10, J12, J14, J16, J18, J20, J22, J24, J26, J28, J30, J32: 1X08_NO_SILK
LOGO1, LOGO3, LOGO4, LOGO6, LOGO7, LOGO9, LOGO10, LOGO12, LOGO13, LOGO15, LOGO16, LOGO18, LOGO19, LOGO21, LOGO22, LOGO24, LOGO25, LOGO27, LOGO28, LOGO30, LOGO31, LOGO33, LOGO34, LOGO36, LOGO37, LOGO39, LOGO40, LOGO42, LOGO43, LOGO45, LOGO46, LOGO48: SPARKX-LOGO5; SPARKX-LARGE
LOGO2, LOGO5, LOGO8, LOGO11, LOGO14, LOGO17, LOGO20, LOGO23, LOGO26, LOGO29, LOGO32, LOGO35, LOGO38, LOGO41, LOGO44, LOGO47: OSHW-LOGOM; OSHW-LOGO-M
R1, R2, R3, R4, R5, R6, R7, R8, R9, R10, R11, R12, R13, R14, R15, R16: 100k; 0603
U1, U3, U7, U10, U13, U16, U19, U22, U25, U28, U31, U34, U37, U40, U43, U46: A111
U2, U5, U8, U11, U14, U17, U20, U23, U26, U29, U32, U35, U38, U41, U44, U47: V_REG_AP2112K-1.8; SOT23-5
U4, U6, U9, U12, U15, U18, U21, U24, U27, U30, U33, U36, U39, U42, U45, U48: TXB0108DQSR; UFDFN-20
U$1, U$9, U$29, U$30, U$46, U$47, U$63, U$64, U$80, U$81, U$97, U$98, U$114, U$115, U$131, U$132, U$148, U$149, U$165, U$166, U$182, U$183, U$199, U$200, U$216, U$217, U$233, U$234, U$250, U$251, U$267, U$268: A111_PULSED_RADAR9
U$2, U$10, U$14, U$24, U$35, U$41, U$52, U$58, U$69, U$75, U$86, U$92, U$103, U$109, U$120, U$126, U$137, U$143, U$154, U$160, U$171, U$177, U$188, U$194, U$205, U$211, U$222, U$228, U$239, U$245, U$256, U$262: SCLK3
U$3, U$11, U$19, U$25, U$36, U$42, U$53, U$59, U$70, U$76, U$87, U$93, U$104, U$110, U$121, U$127, U$138, U$144, U$155, U$161, U$172, U$178, U$189, U$195, U$206, U$212, U$223, U$229, U$240, U$246, U$257, U$263: MISO4
U$4, U$20, U$37, U$54, U$71, U$88, U$105, U$122, U$139, U$156, U$173, U$190, U$207, U$224, U$241, U$258: MOSI5
U$5, U$21, U$38, U$55, U$72, U$89, U$106, U$123, U$140, U$157, U$174, U$191, U$208, U$225, U$242, U$259: INT8
U$6, U$18, U$33, U$34, U$50, U$51, U$67, U$68, U$84, U$85, U$101, U$102, U$118, U$119, U$135, U$136, U$152, U$153, U$169, U$170, U$186, U$187, U$203, U$204, U$220, U$221, U$237, U$238, U$254, U$255, U$271, U$272: EN9
U$7, U$15, U$22, U$26, U$39, U$43, U$56, U$60, U$73, U$77, U$90, U$94, U$107, U$111, U$124, U$128, U$141, U$145, U$158, U$162, U$175, U$179, U$192, U$196, U$209, U$213, U$226, U$230, U$243, U$247, U$260, U$264: GND0
U$8, U$16, U$23, U$27, U$40, U$44, U$57, U$61, U$74, U$78, U$91, U$95, U$108, U$112, U$125, U$129, U$142, U$146, U$159, U$163, U$176, U$180, U$193, U$197, U$210, U$214, U$227, U$231, U$244, U$248, U$261, U$265: 5V1
U$12, U$31, U$48, U$65, U$82, U$99, U$116, U$133, U$150, U$167, U$184, U$201, U$218, U$235, U$252, U$269: PI_DISPLAY9
U$13, U$17, U$28, U$32, U$45, U$49, U$62, U$66, U$79, U$83, U$96, U$100, U$113, U$117, U$130, U$134, U$147, U$151, U$164, U$168, U$181, U$185, U$198, U$202, U$215, U$219, U$232, U$236, U$249, U$253, U$266, U$270: #CS9
Y1, Y2, Y3, Y4, Y5, Y6, Y7, Y8, Y9, Y10, Y11, Y12, Y13, Y14, Y15, Y16: 26MHz; CRYSTAL-SMD-3.2X2.5MM

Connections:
1.8V: C1.1, C2.1, C5.1, C6.1, C7.1, C8.1, C10.1, U1.C2, U1.C9, U1.D1, U1.D10, U1.J1, U1.J9, U1.K9, U2.5, U4.5, U4.6
1.8V1: C11.1, C12.1, C15.1, C16.1, C17.1, C18.1, C20.1, U3.C2, U3.C9, U3.D1, U3.D10, U3.J1, U3.J9, U3.K9, U5.5, U6.5, U6.6
1.8V2: C21.1, C22.1, C25.1, C26.1, C27.1, C28.1, C30.1, U7.C2, U7.C9, U7.D1, U7.D10, U7.J1, U7.J9, U7.K9, U8.5, U9.5, U9.6
1.8V3: C31.1, C32.1, C35.1, C36.1, C37.1, C38.1, C40.1, U10.C2, U10.C9, U10.D1, U10.D10, U10.J1, U10.J9, U10.K9, U11.5, U12.5, U12.6
1.8V4: C41.1, C42.1, C45.1, C46.1, C47.1, C48.1, C50.1, U13.C2, U13.C9, U13.D1, U13.D10, U13.J1, U13.J9, U13.K9, U14.5, U15.5, U15.6
1.8V5: C51.1, C52.1, C55.1, C56.1, C57.1, C58.1, C60.1, U16.C2, U16.C9, U16.D1, U16.D10, U16.J1, U16.J9, U16.K9, U17.5, U18.5, U18.6
1.8V6: C61.1, C62.1, C65.1, C66.1, C67.1, C68.1, C70.1, U19.C2, U19.C9, U19.D1, U19.D10, U19.J1, U19.J9, U19.K9, U20.5, U21.5, U21.6
1.8V7: C71.1, C72.1, C75.1, C76.1, C77.1, C78.1, C80.1, U22.C2, U22.C9, U22.D1, U22.D10, U22.J1, U22.J9, U22.K9, U23.5, U24.5, U24.6
1.8V8: C81.1, C82.1, C85.1, C86.1, C87.1, C88.1, C90.1, U25.C2, U25.C9, U25.D1, U25.D10, U25.J1, U25.J9, U25.K9, U26.5, U27.5, U27.6
1.8V9: C91.1, C92.1, C95.1, C96.1, C97.1, C98.1, C100.1, U28.C2, U28.C9, U28.D1, U28.D10, U28.J1, U28.J9, U28.K9, U29.5, U30.5, U30.6
1.8V10: C101.1, C102.1, C105.1, C106.1, C107.1, C108.1, C110.1, U31.C2, U31.C9, U31.D1, U31.D10, U31.J1, U31.J9, U31.K9, U32.5, U33.5, U33.6
1.8V11: C111.1, C112.1, C115.1, C116.1, C117.1, C118.1, C120.1, U34.C2, U34.C9, U34.D1, U34.D10, U34.J1, U34.J9, U34.K9, U35.5, U36.5, U36.6
1.8V12: C121.1, C122.1, C125.1, C126.1, C127.1, C128.1, C130.1, U37.C2, U37.C9, U37.D1, U37.D10, U37.J1, U37.J9, U37.K9, U38.5, U39.5, U39.6
1.8V13: C131.1, C132.1, C135.1, C136.1, C137.1, C138.1, C140.1, U40.C2, U40.C9, U40.D1, U40.D10, U40.J1, U40.J9, U40.K9, U41.5, U42.5, U42.6
1.8V14: C141.1, C142.1, C145.1, C146.1, C147.1, C148.1, C150.1, U43.C2, U43.C9, U43.D1, U43.D10, U43.J1, U43.J9, U43.K9, U44.5, U45.5, U45.6
1.8V15: C151.1, C152.1, C155.1, C156.1, C157.1, C158.1, C160.1, U46.C2, U46.C9, U46.D1, U46.D10, U46.J1, U46.J9, U46.K9, U47.5, U48.5, U48.6
5V: C9.1, J2.1, J4.2, J4.4, U2.1, U2.3, U4.16
5V1: C19.1, J1.2, J1.4, J3.1, U5.1, U5.3, U6.16
5V2: C29.1, J5.2, J5.4, J6.1, U8.1, U8.3, U9.16
5V3: C39.1, J7.2, J7.4, J8.1, U11.1, U11.3, U12.16
5V4: C49.1, J9.2, J9.4, J10.1, U14.1, U14.3, U15.16
5V5: C59.1, J11.2, J11.4, J12.1, U17.1, U17.3, U18.16
5V6: C69.1, J13.2, J13.4, J14.1, U20.1, U20.3, U21.16
5V7: C79.1, J15.2, J15.4, J16.1, U23.1, U23.3, U24.16
5V8: C89.1, J17.2, J17.4, J18.1, U26.1, U26.3, U27.16
5V9: C99.1, J19.2, J19.4, J20.1, U29.1, U29.3, U30.16
5V10: C109.1, J21.2, J21.4, J22.1, U32.1, U32.3, U33.16
5V11: C119.1, J23.2, J23.4, J24.1, U35.1, U35.3, U36.16
5V12: C129.1, J25.2, J25.4, J26.1, U38.1, U38.3, U39.16
5V13: C139.1, J27.2, J27.4, J28.1, U41.1, U41.3, U42.16
5V14: C149.1, J29.2, J29.4, J30.1, U44.1, U44.3, U45.16
5V15: C159.1, J31.2, J31.4, J32.1, U47.1, U47.3, U48.16
!CS!: U1.J2, U4.1
!CS!1: U3.J2, U6.1
!CS!2: U7.J2, U9.1
!CS!3: U10.J2, U12.1
!CS!4: U13.J2, U15.1
!CS!5: U16.J2, U18.1
!CS!6: U19.J2, U21.1
!CS!7: U22.J2, U24.1
!CS!8: U25.J2, U27.1
!CS!9: U28.J2, U30.1
!CS!10: U31.J2, U33.1
!CS!11: U34.J2, U36.1
!CS!12: U37.J2, U39.1
!CS!13: U40.J2, U42.1
!CS!14: U43.J2, U45.1
!CS!15: U46.J2, U48.1
!CS!_RPI: J2.8, J4.24, U4.20
!CS!_RPI1: J1.24, J3.8, U6.20
!CS!_RPI2: J5.24, J6.8, U9.20
!CS!_RPI3: J7.24, J8.8, U12.20
!CS!_RPI4: J9.24, J10.8, U15.20
!CS!_RPI5: J11.24, J12.8, U18.20
!CS!_RPI6: J13.24, J14.8, U21.20
!CS!_RPI7: J15.24, J16.8, U24.20
!CS!_RPI8: J17.24, J18.8, U27.20
!CS!_RPI9: J19.24, J20.8, U30.20
!CS!_RPI10: J21.24, J22.8, U33.20
!CS!_RPI11: J23.24, J24.8, U36.20
!CS!_RPI12: J25.24, J26.8, U39.20
!CS!_RPI13: J27.24, J28.8, U42.20
!CS!_RPI14: J29.24, J30.8, U45.20
!CS!_RPI15: J31.24, J32.8, U48.20
ENABLE: U1.F10, U4.10
ENABLE1: U3.F10, U6.10
ENABLE2: U7.F10, U9.10
ENABLE3: U10.F10, U12.10
ENABLE4: U13.F10, U15.10
ENABLE5: U16.F10, U18.10
ENABLE6: U19.F10, U21.10
ENABLE7: U22.F10, U24.10
ENABLE8: U25.F10, U27.10
ENABLE9: U28.F10, U30.10
ENABLE10: U31.F10, U33.10
ENABLE11: U34.F10, U36.10
ENABLE12: U37.F10, U39.10
ENABLE13: U40.F10, U42.10
ENABLE14: U43.F10, U45.10
ENABLE15: U46.F10, U48.10
ENABLE_RPI: J2.3, J4.13, U4.11
ENABLE_RPI1: J1.13, J3.3, U6.11
ENABLE_RPI2: J5.13, J6.3, U9.11
ENABLE_RPI3: J7.13, J8.3, U12.11
ENABLE_RPI4: J9.13, J10.3, U15.11
ENABLE_RPI5: J11.13, J12.3, U18.11
ENABLE_RPI6: J13.13, J14.3, U21.11
ENABLE_RPI7: J15.13, J16.3, U24.11
ENABLE_RPI8: J17.13, J18.3, U27.11
ENABLE_RPI9: J19.13, J20.3, U30.11
ENABLE_RPI10: J21.13, J22.3, U33.11
ENABLE_RPI11: J23.13, J24.3, U36.11
ENABLE_RPI12: J25.13, J26.3, U39.11
ENABLE_RPI13: J27.13, J28.3, U42.11
ENABLE_RPI14: J29.13, J30.3, U45.11
ENABLE_RPI15: J31.13, J32.3, U48.11
GND: C1.2, C2.2, C3.2, C4.1, C5.2, C6.2, C7.2, C8.2, C9.2, C10.2, J2.2, J4.6, J4.9, J4.14, J4.20, J4.25, R1.1, U1.A3, U1.A4, U1.A5, U1.A6, U1.A7, U1.A8, U1.A9, U1.B2, U1.B9, U1.B10, U1.C1, U1.C10, U1.D2, U1.D9, U1.E1, U1.E2, U1.E9, U1.E10, U1.F1, U1.F2, U1.F9, U1.G1, U1.G10, U1.H1, U1.H2, U1.H9, U1.J3, U1.J5, U1.J6, U1.J8, U1.K4, U1.K5, U1.K7, U4.15, Y1.2, Y1.4
GND1: C11.2, C12.2, C13.2, C14.1, C15.2, C16.2, C17.2, C18.2, C19.2, C20.2, J1.6, J1.9, J1.14, J1.20, J1.25, J3.2, R2.1, U3.A3, U3.A4, U3.A5, U3.A6, U3.A7, U3.A8, U3.A9, U3.B2, U3.B9, U3.B10, U3.C1, U3.C10, U3.D2, U3.D9, U3.E1, U3.E2, U3.E9, U3.E10, U3.F1, U3.F2, U3.F9, U3.G1, U3.G10, U3.H1, U3.H2, U3.H9, U3.J3, U3.J5, U3.J6, U3.J8, U3.K4, U3.K5, U3.K7, U6.15, Y2.2, Y2.4
GND2: C21.2, C22.2, C23.2, C24.1, C25.2, C26.2, C27.2, C28.2, C29.2, C30.2, J5.6, J5.9, J5.14, J5.20, J5.25, J6.2, R3.1, U7.A3, U7.A4, U7.A5, U7.A6, U7.A7, U7.A8, U7.A9, U7.B2, U7.B9, U7.B10, U7.C1, U7.C10, U7.D2, U7.D9, U7.E1, U7.E2, U7.E9, U7.E10, U7.F1, U7.F2, U7.F9, U7.G1, U7.G10, U7.H1, U7.H2, U7.H9, U7.J3, U7.J5, U7.J6, U7.J8, U7.K4, U7.K5, U7.K7, U9.15, Y3.2, Y3.4
GND3: C31.2, C32.2, C33.2, C34.1, C35.2, C36.2, C37.2, C38.2, C39.2, C40.2, J7.6, J7.9, J7.14, J7.20, J7.25, J8.2, R4.1, U10.A3, U10.A4, U10.A5, U10.A6, U10.A7, U10.A8, U10.A9, U10.B2, U10.B9, U10.B10, U10.C1, U10.C10, U10.D2, U10.D9, U10.E1, U10.E2, U10.E9, U10.E10, U10.F1, U10.F2, U10.F9, U10.G1, U10.G10, U10.H1, U10.H2, U10.H9, U10.J3, U10.J5, U10.J6, U10.J8, U10.K4, U10.K5, U10.K7, U12.15, Y4.2, Y4.4
GND4: C41.2, C42.2, C43.2, C44.1, C45.2, C46.2, C47.2, C48.2, C49.2, C50.2, J9.6, J9.9, J9.14, J9.20, J9.25, J10.2, R5.1, U13.A3, U13.A4, U13.A5, U13.A6, U13.A7, U13.A8, U13.A9, U13.B2, U13.B9, U13.B10, U13.C1, U13.C10, U13.D2, U13.D9, U13.E1, U13.E2, U13.E9, U13.E10, U13.F1, U13.F2, U13.F9, U13.G1, U13.G10, U13.H1, U13.H2, U13.H9, U13.J3, U13.J5, U13.J6, U13.J8, U13.K4, U13.K5, U13.K7, U15.15, Y5.2, Y5.4
GND5: C51.2, C52.2, C53.2, C54.1, C55.2, C56.2, C57.2, C58.2, C59.2, C60.2, J11.6, J11.9, J11.14, J11.20, J11.25, J12.2, R6.1, U16.A3, U16.A4, U16.A5, U16.A6, U16.A7, U16.A8, U16.A9, U16.B2, U16.B9, U16.B10, U16.C1, U16.C10, U16.D2, U16.D9, U16.E1, U16.E2, U16.E9, U16.E10, U16.F1, U16.F2, U16.F9, U16.G1, U16.G10, U16.H1, U16.H2, U16.H9, U16.J3, U16.J5, U16.J6, U16.J8, U16.K4, U16.K5, U16.K7, U18.15, Y6.2, Y6.4
GND6: C61.2, C62.2, C63.2, C64.1, C65.2, C66.2, C67.2, C68.2, C69.2, C70.2, J13.6, J13.9, J13.14, J13.20, J13.25, J14.2, R7.1, U19.A3, U19.A4, U19.A5, U19.A6, U19.A7, U19.A8, U19.A9, U19.B2, U19.B9, U19.B10, U19.C1, U19.C10, U19.D2, U19.D9, U19.E1, U19.E2, U19.E9, U19.E10, U19.F1, U19.F2, U19.F9, U19.G1, U19.G10, U19.H1, U19.H2, U19.H9, U19.J3, U19.J5, U19.J6, U19.J8, U19.K4, U19.K5, U19.K7, U21.15, Y7.2, Y7.4
GND7: C71.2, C72.2, C73.2, C74.1, C75.2, C76.2, C77.2, C78.2, C79.2, C80.2, J15.6, J15.9, J15.14, J15.20, J15.25, J16.2, R8.1, U22.A3, U22.A4, U22.A5, U22.A6, U22.A7, U22.A8, U22.A9, U22.B2, U22.B9, U22.B10, U22.C1, U22.C10, U22.D2, U22.D9, U22.E1, U22.E2, U22.E9, U22.E10, U22.F1, U22.F2, U22.F9, U22.G1, U22.G10, U22.H1, U22.H2, U22.H9, U22.J3, U22.J5, U22.J6, U22.J8, U22.K4, U22.K5, U22.K7, U24.15, Y8.2, Y8.4
GND8: C81.2, C82.2, C83.2, C84.1, C85.2, C86.2, C87.2, C88.2, C89.2, C90.2, J17.6, J17.9, J17.14, J17.20, J17.25, J18.2, R9.1, U25.A3, U25.A4, U25.A5, U25.A6, U25.A7, U25.A8, U25.A9, U25.B2, U25.B9, U25.B10, U25.C1, U25.C10, U25.D2, U25.D9, U25.E1, U25.E2, U25.E9, U25.E10, U25.F1, U25.F2, U25.F9, U25.G1, U25.G10, U25.H1, U25.H2, U25.H9, U25.J3, U25.J5, U25.J6, U25.J8, U25.K4, U25.K5, U25.K7, U27.15, Y9.2, Y9.4
GND9: C91.2, C92.2, C93.2, C94.1, C95.2, C96.2, C97.2, C98.2, C99.2, C100.2, J19.6, J19.9, J19.14, J19.20, J19.25, J20.2, R10.1, U28.A3, U28.A4, U28.A5, U28.A6, U28.A7, U28.A8, U28.A9, U28.B2, U28.B9, U28.B10, U28.C1, U28.C10, U28.D2, U28.D9, U28.E1, U28.E2, U28.E9, U28.E10, U28.F1, U28.F2, U28.F9, U28.G1, U28.G10, U28.H1, U28.H2, U28.H9, U28.J3, U28.J5, U28.J6, U28.J8, U28.K4, U28.K5, U28.K7, U30.15, Y10.2, Y10.4
GND10: C101.2, C102.2, C103.2, C104.1, C105.2, C106.2, C107.2, C108.2, C109.2, C110.2, J21.6, J21.9, J21.14, J21.20, J21.25, J22.2, R11.1, U31.A3, U31.A4, U31.A5, U31.A6, U31.A7, U31.A8, U31.A9, U31.B2, U31.B9, U31.B10, U31.C1, U31.C10, U31.D2, U31.D9, U31.E1, U31.E2, U31.E9, U31.E10, U31.F1, U31.F2, U31.F9, U31.G1, U31.G10, U31.H1, U31.H2, U31.H9, U31.J3, U31.J5, U31.J6, U31.J8, U31.K4, U31.K5, U31.K7, U33.15, Y11.2, Y11.4
GND11: C111.2, C112.2, C113.2, C114.1, C115.2, C116.2, C117.2, C118.2, C119.2, C120.2, J23.6, J23.9, J23.14, J23.20, J23.25, J24.2, R12.1, U34.A3, U34.A4, U34.A5, U34.A6, U34.A7, U34.A8, U34.A9, U34.B2, U34.B9, U34.B10, U34.C1, U34.C10, U34.D2, U34.D9, U34.E1, U34.E2, U34.E9, U34.E10, U34.F1, U34.F2, U34.F9, U34.G1, U34.G10, U34.H1, U34.H2, U34.H9, U34.J3, U34.J5, U34.J6, U34.J8, U34.K4, U34.K5, U34.K7, U36.15, Y12.2, Y12.4
GND12: C121.2, C122.2, C123.2, C124.1, C125.2, C126.2, C127.2, C128.2, C129.2, C130.2, J25.6, J25.9, J25.14, J25.20, J25.25, J26.2, R13.1, U37.A3, U37.A4, U37.A5, U37.A6, U37.A7, U37.A8, U37.A9, U37.B2, U37.B9, U37.B10, U37.C1, U37.C10, U37.D2, U37.D9, U37.E1, U37.E2, U37.E9, U37.E10, U37.F1, U37.F2, U37.F9, U37.G1, U37.G10, U37.H1, U37.H2, U37.H9, U37.J3, U37.J5, U37.J6, U37.J8, U37.K4, U37.K5, U37.K7, U39.15, Y13.2, Y13.4
GND13: C131.2, C132.2, C133.2, C134.1, C135.2, C136.2, C137.2, C138.2, C139.2, C140.2, J27.6, J27.9, J27.14, J27.20, J27.25, J28.2, R14.1, U40.A3, U40.A4, U40.A5, U40.A6, U40.A7, U40.A8, U40.A9, U40.B2, U40.B9, U40.B10, U40.C1, U40.C10, U40.D2, U40.D9, U40.E1, U40.E2, U40.E9, U40.E10, U40.F1, U40.F2, U40.F9, U40.G1, U40.G10, U40.H1, U40.H2, U40.H9, U40.J3, U40.J5, U40.J6, U40.J8, U40.K4, U40.K5, U40.K7, U42.15, Y14.2, Y14.4
GND14: C141.2, C142.2, C143.2, C144.1, C145.2, C146.2, C147.2, C148.2, C149.2, C150.2, J29.6, J29.9, J29.14, J29.20, J29.25, J30.2, R15.1, U43.A3, U43.A4, U43.A5, U43.A6, U43.A7, U43.A8, U43.A9, U43.B2, U43.B9, U43.B10, U43.C1, U43.C10, U43.D2, U43.D9, U43.E1, U43.E2, U43.E9, U43.E10, U43.F1, U43.F2, U43.F9, U43.G1, U43.G10, U43.H1, U43.H2, U43.H9, U43.J3, U43.J5, U43.J6, U43.J8, U43.K4, U43.K5, U43.K7, U45.15, Y15.2, Y15.4
GND15: C151.2, C152.2, C153.2, C154.1, C155.2, C156.2, C157.2, C158.2, C159.2, C160.2, J31.6, J31.9, J31.14, J31.20, J31.25, J32.2, R16.1, U46.A3, U46.A4, U46.A5, U46.A6, U46.A7, U46.A8, U46.A9, U46.B2, U46.B9, U46.B10, U46.C1, U46.C10, U46.D2, U46.D9, U46.E1, U46.E2, U46.E9, U46.E10, U46.F1, U46.F2, U46.F9, U46.G1, U46.G10, U46.H1, U46.H2, U46.H9, U46.J3, U46.J5, U46.J6, U46.J8, U46.K4, U46.K5, U46.K7, U48.15, Y16.2, Y16.4
INTERRUPT: R1.2, U1.K8, U4.9
INTERRUPT1: R2.2, U3.K8, U6.9
INTERRUPT2: R3.2, U7.K8, U9.9
INTERRUPT3: R4.2, U10.K8, U12.9
INTERRUPT4: R5.2, U13.K8, U15.9
INTERRUPT5: R6.2, U16.K8, U18.9
INTERRUPT6: R7.2, U19.K8, U21.9
INTERRUPT7: R8.2, U22.K8, U24.9
INTERRUPT8: R9.2, U25.K8, U27.9
INTERRUPT9: R10.2, U28.K8, U30.9
INTERRUPT10: R11.2, U31.K8, U33.9
INTERRUPT11: R12.2, U34.K8, U36.9
INTERRUPT12: R13.2, U37.K8, U39.9
INTERRUPT13: R14.2, U40.K8, U42.9
INTERRUPT14: R15.2, U43.K8, U45.9
INTERRUPT15: R16.2, U46.K8, U48.9
INTERRUPT_RPI: J2.4, J4.22, U4.12
INTERRUPT_RPI1: J1.22, J3.4, U6.12
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

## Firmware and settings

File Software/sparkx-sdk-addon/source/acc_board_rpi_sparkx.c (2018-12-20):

// Copyright (c) Acconeer AB, 2017-2018
// All rights reserved

#include <stdbool.h>
#include <stdint.h>
#include <stdlib.h>

#include "acc_board.h"
#include "acc_device_gpio.h"
#include "acc_device_os.h"
#include "acc_device_spi.h"
#include "acc_driver_gpio_linux_sysfs.h"
#include "acc_driver_os_linux.h"
#include "acc_driver_spi_linux_spidev.h"
#include "acc_log.h"


/**
 * @brief The module name
 *
 * Must exist if acc_log.h is used.
 */
#define MODULE		"acc_board_rpi_sparkx-3_r1c"

/**
 * @brief The number of sensors available on the board
 */
#define SENSOR_COUNT	1

/**
 * @brief Host GPIO pin number (BCM)
 *
 * This GPIO should be connected to sensor 1 GPIO 5
 */
#define GPIO0_PIN	25      // Interrupt pin

/**
 * @brief Host GPIO pin number (BCM)
 */
/**@{*/
#define RSTn_PIN	6        // Not connected
#define ENABLE_PIN	27

//#define CE_PIN      8        // Breakout CS pin
/**@}*/

/**
 * @brief The reference frequency used by this board
 *
 * This assumes 24 MHz on XR111-3 R1C
 */
#define ACC_BOARD_REF_FREQ	26000000

/**
 * @brief The SPI speed of this board
 */
#define ACC_BOARD_SPI_SPEED	15000000

/**
 * @brief The SPI bus all sensors are using
 */
#define ACC_BOARD_BUS		0

/**
 * @brief The SPI CS all sensors are using
 */
#define ACC_BOARD_CS		0

/**
 * @brief Number of GPIO pins
 */
#define GPIO_PIN_COUNT 28


/**
 * @brief Sensor states
 */
typedef enum {
	SENSOR_STATE_UNKNOWN,
	SENSOR_STATE_READY,
	SENSOR_STATE_BUSY
} acc_board_sensor_state_t;


/**
 * @brief Sensor state collection that keeps track of each sensor's current state
 */
static acc_board_sensor_state_t sensor_state[SENSOR_COUNT] = {SENSOR_STATE_UNKNOWN};


static const uint_fast8_t sensor_interrupt_pins[SENSOR_COUNT] = {
	GPIO0_PIN
};


static acc_board_isr_t master_isr;
static acc_device_handle_t spi_handle;
static gpio_t              gpios[GPIO_PIN_COUNT];

static void isr_sensor1(void)
{
	if (master_isr)
	{
		master_isr(1);
	}
}


/**
 * @brief Get the combined status of all sensors
 *
 * @return False if any sensor is busy
 */
static bool acc_board_all_sensors_inactive(void)
{
	for (uint_fast8_t sensor_index = 0; sensor_index < SENSOR_COUNT; sensor_index++)
	{
		if (sensor_state[sensor_index] == SENSOR_STATE_BUSY)
		{
			return false;
		}
	}

	return true;
}


acc_status_t acc_board_gpio_init(void)
{
	static bool		init_done = false;
	static acc_os_mutex_t	init_mutex = NULL;

	if (init_done)
	{
		return ACC_STATUS_SUCCESS;
	}

	acc_os_init();
	init_mutex = acc_os_mutex_create();

	acc_os_mutex_lock(init_mutex);

	if (init_done)
	{
		acc_os_mutex_unlock(init_mutex);
		return ACC_STATUS_SUCCESS;
	}

	if (
		!acc_device_gpio_set_initial_pull(GPIO0_PIN, 0) ||
		!acc_device_gpio_set_initial_pull(RSTn_PIN, 1) ||
		!acc_device_gpio_set_initial_pull(ENABLE_PIN, 0))
	{
		ACC_LOG_WARNING("%s: failed to set initial pull", __func__);
	}

	if (
		!acc_device_gpio_input(GPIO0_PIN) ||
		!acc_device_gpio_write(RSTn_PIN, 0) ||
		!acc_device_gpio_write(ENABLE_PIN, 0))
	{
		acc_os_mutex_unlock(init_mutex);
		return ACC_STATUS_FAILURE;
	}

	init_done = true;
	acc_os_mutex_unlock(init_mutex);

	return ACC_STATUS_SUCCESS;
}


acc_status_t acc_board_init(void)
{
	static bool		init_done = false;
	static acc_os_mutex_t	init_mutex = NULL;

	if (init_done)
	{
		return ACC_STATUS_SUCCESS;
	}

	acc_driver_os_linux_register();
	acc_os_init();
	init_mutex = acc_os_mutex_create();

	acc_os_mutex_lock(init_mutex);

	if (init_done)
	{
		acc_os_mutex_unlock(init_mutex);
		return ACC_STATUS_SUCCESS;
	}

	acc_driver_gpio_linux_sysfs_register(GPIO_PIN_COUNT, gpios);
	acc_driver_spi_linux_spidev_register();

	acc_device_gpio_init();

	acc_device_spi_configuration_t configuration;

	configuration.bus           = ACC_BOARD_BUS;
	configuration.configuration = NULL;
	configuration.device        = ACC_BOARD_CS;
	configuration.master        = true;
	configuration.speed         = ACC_BOARD_SPI_SPEED;

	spi_handle = acc_device_spi_create(&configuration);

	for (uint_fast8_t sensor_index = 0; sensor_index < SENSOR_COUNT; sensor_index++)
	{
		sensor_state[sensor_index] = SENSOR_STATE_UNKNOWN;
	}

	init_done = true;
	acc_os_mutex_unlock(init_mutex);

	return ACC_STATUS_SUCCESS;
}


/**
 * @brief Reset sensor
 *
 * Default setup when sensor is not active
 *
 * @return Status
 */
static acc_status_t acc_board_reset_sensor(void)
{
	if (!acc_device_gpio_write(RSTn_PIN, 0))
	{
		ACC_LOG_ERROR("Unable to activate RSTn");
		return ACC_STATUS_FAILURE;
	}

	if (!acc_device_gpio_write(ENABLE_PIN, 0))
	{
		ACC_LOG_ERROR("Unable to deactivate ENABLE");
		return ACC_STATUS_FAILURE;
	}

	return ACC_STATUS_SUCCESS;
}
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

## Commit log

2018-05-24 Initial commit of hardware layout.
    [A111_Pulsed_Radar_Breakout.brd, A111_Pulsed_Radar_Breakout.sch]
2018-05-24 Adding 5x5 production panel.
    [A111_Pulsed_Radar_Breakout-Panel.GBL, A111_Pulsed_Radar_Breakout-Panel.GBO, A111_Pulsed_Radar_Breakout-Panel.GBP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]
2018-07-27 Initial commit of example distance detector, board source, and makefiles.
2018-11-26 Updating board source and make rules for compatibility with SDK v1.3.11
2018-12-20 Updating SparkX board source file for SDK 1.4.0

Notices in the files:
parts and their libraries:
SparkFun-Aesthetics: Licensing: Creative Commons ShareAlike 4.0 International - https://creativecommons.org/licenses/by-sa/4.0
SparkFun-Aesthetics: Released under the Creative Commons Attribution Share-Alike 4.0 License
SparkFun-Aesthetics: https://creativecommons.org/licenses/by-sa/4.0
